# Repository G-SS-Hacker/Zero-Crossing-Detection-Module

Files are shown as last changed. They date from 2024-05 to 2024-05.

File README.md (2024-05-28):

# Zero-Crossing-Detection-Module 

> **交流电压过零检测模块**

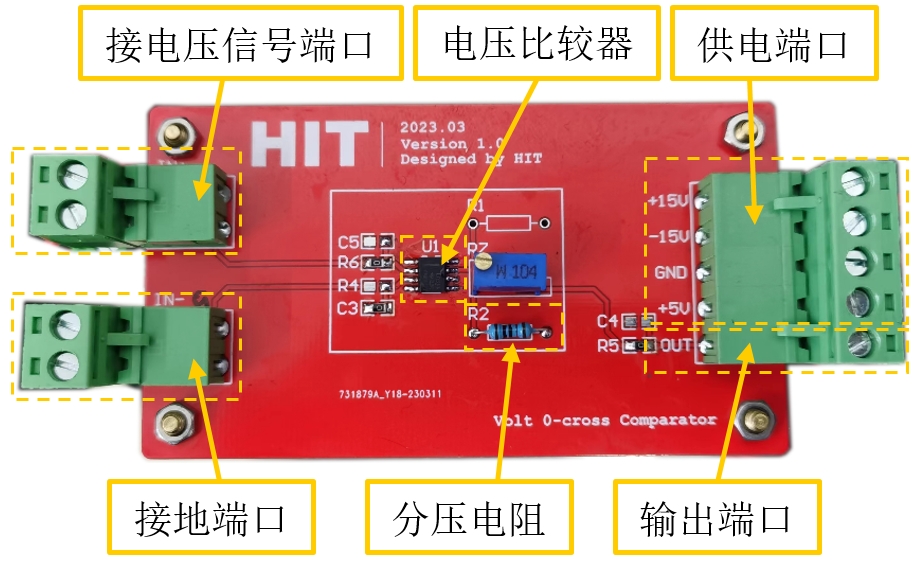
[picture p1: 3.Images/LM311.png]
LM311


## 总体方案

基于LM311D的电压过零比较器/过零检测模块，输出电压过零中断信号，可以用于低压配电电路过零/选相合闸。

过零检测模块由电压信号端口、接地端口、电压比较器芯片、分压电阻、供电端口和输出端口组成。PCB长9cm、宽5cm。

过零检测原理：LM311电压比较器芯片内部由一个运放和一个NPN型三极管构成，运放的输出端连接NPN三极管基极。运放输入正向端电压大于反向端时，三极管导通；反之，三极管关断。将外部信号连接至运放输入正向端，GND连接至运放输入反向端，配合工作于开关状态的三极管，即可实现过零检测。

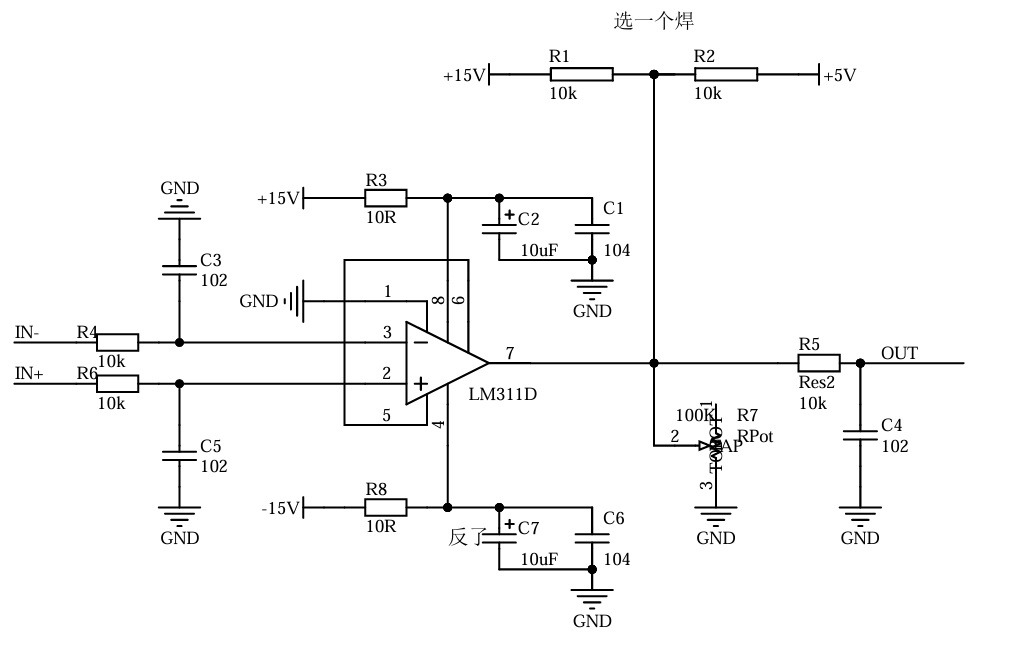
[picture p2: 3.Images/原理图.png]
原理图


## 典型应用

> **硬件过零比较锁相/选相合闸**

电压信号端口接交流电压传感器输出端；C3，C5为输入信号RC低通滤波预留电容焊盘，如果输入信号杂波不严重建议不焊，避免引入延时；类似的，C4为输出信号RC低通滤波预留电容焊盘，如果环境干扰不严重建议不焊，避免引入延时；R1，R2选一个焊（选一个三极管集电极电源），输出信号连接STM32单片机外部中断端口，调节R7使得输出为高电平时，电压3.3V。

选相合闸电路各级波形如下图所示，电压互感器输出波形为周期50ms的正弦波，STM32单片机中断端口接收波形为周期50ms，峰峰值3.3V的方波，STM32单片机内部延时锁相波形为周期50ms，峰峰值360°的三角波。

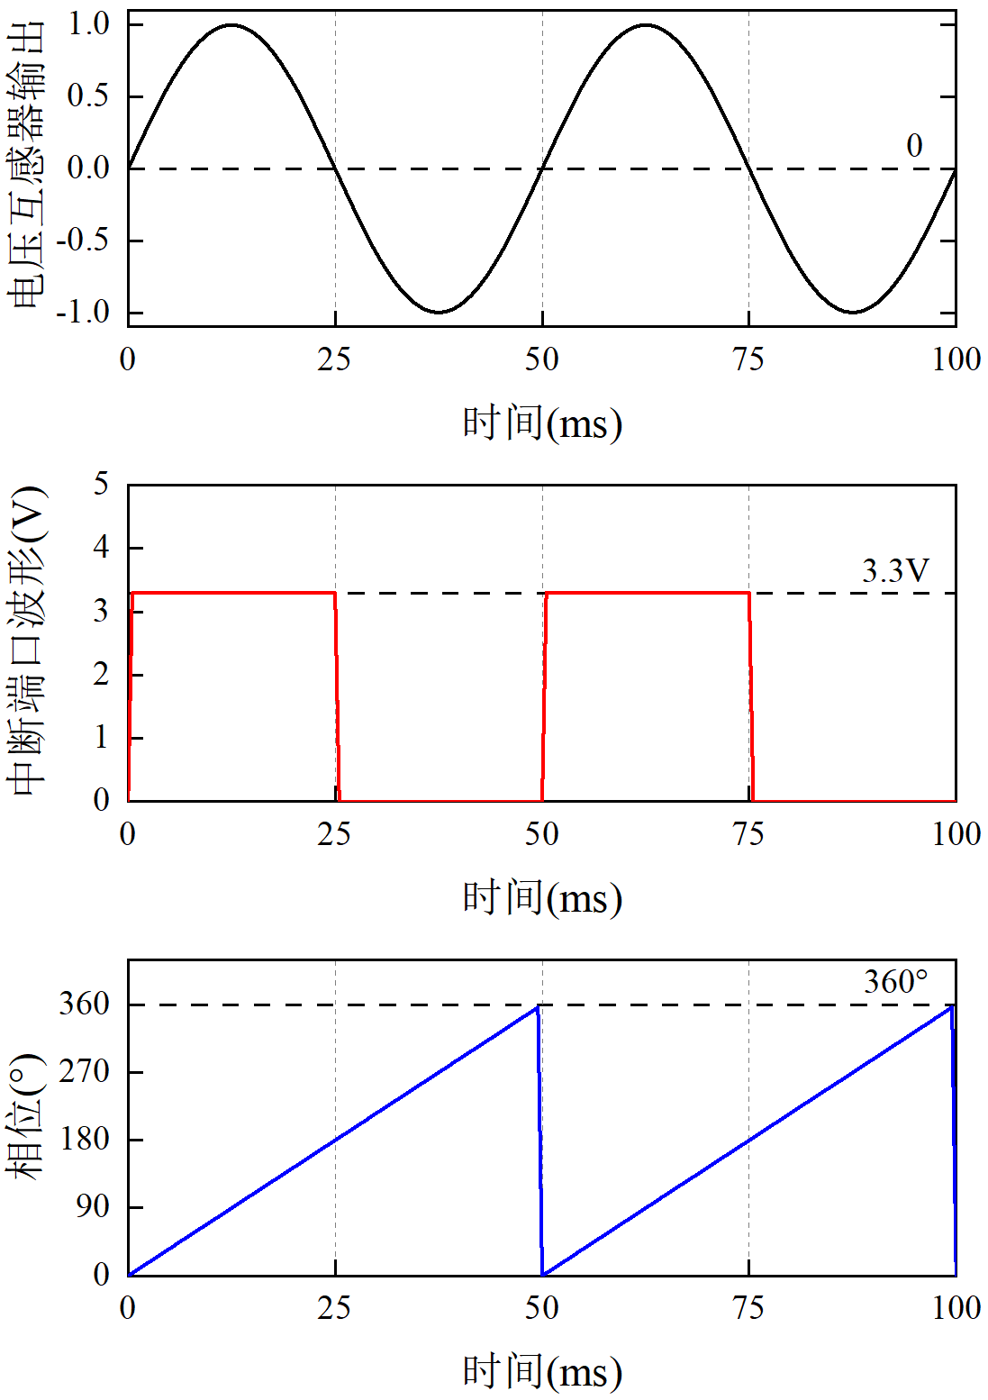
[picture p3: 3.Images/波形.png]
波形


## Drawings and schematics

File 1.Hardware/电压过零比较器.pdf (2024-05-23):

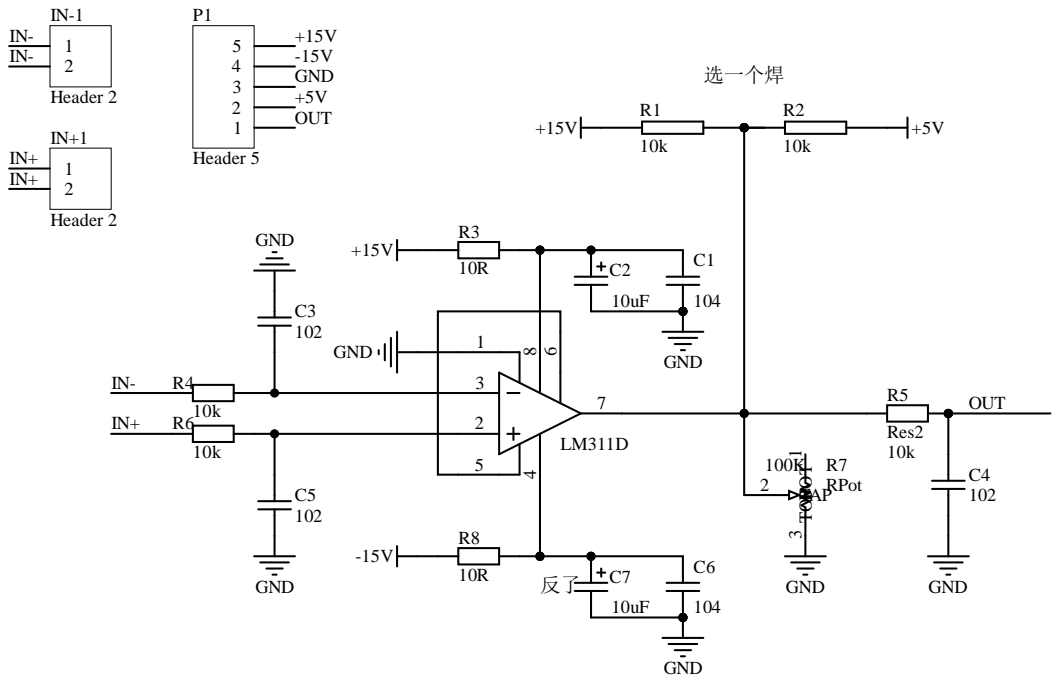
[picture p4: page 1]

IN-1 Header 2 12 IN+1 Header 2

Comment | Description | Designator | Footprint | LibRef | Quantity
Cap | 电容0805 | C1, C3, C4, C5, C6 | 0805 | Cap | 5
Cap Pol2 | Polarized Capacitor (Axial) 1210 | C2, C7 | 1210 | Cap Pol2 | 2
Header 2 | Header, 2-Pin | IN-1, IN+1 | POWER_2PIN 1 | Header 2 | 2
Header 5 | Header, 5-Pin | P1 | POWER_5PIN | Header 5 | 1
10k | 电阻 | R1, R2 | AXIAL-0.4 | RES2 | 2
Res2 | 电阻, Resistor | R3, R4, R5, R6, R8 | 0805 | Res2 | 5
RPot | Potentiometer | R7 | VR5 | RPot | 1
LM311D | | U1 | SO8 | LM311D | 1
